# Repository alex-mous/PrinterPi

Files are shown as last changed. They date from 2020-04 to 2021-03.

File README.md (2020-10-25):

# PrinterPi
### An automatic web parser and packing list printer using a Raspberry Pi and a thermal printer
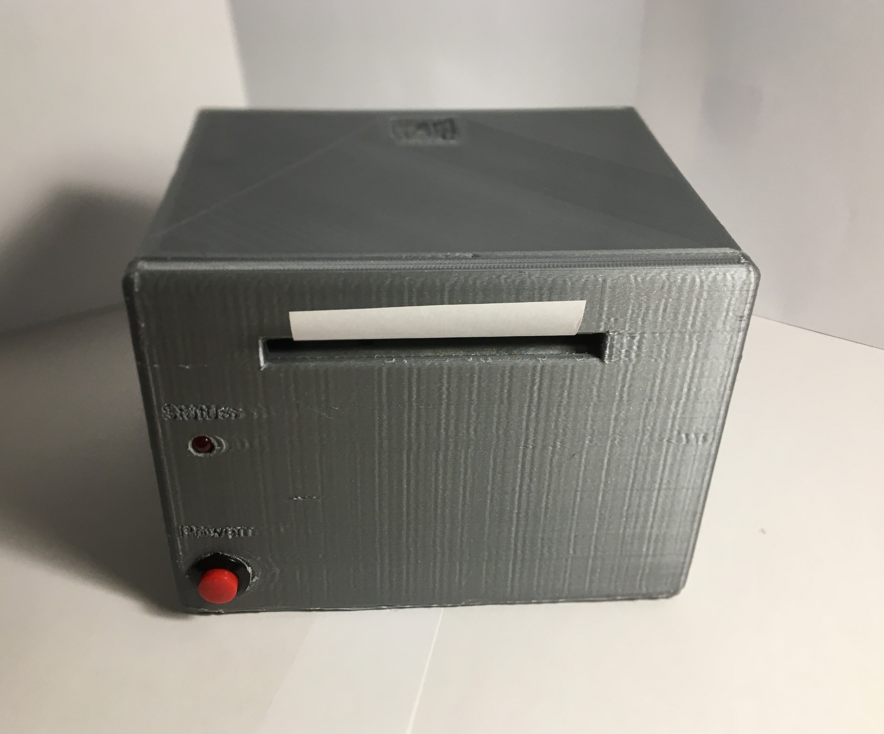
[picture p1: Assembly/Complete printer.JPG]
Completed PrinterPi project


### Parts and Materials
- Raspberry Pi Zero W with [Raspbian Jessie Lite](http://downloads.raspberrypi.org/raspbian_lite/images/raspbian_lite-2017-03-03/2017-03-02-raspbian-jessie-lite.zip) installed (this version is important if you want to make the file system read-only; see the optional last step)
- 3D prints of the files in the "3D Files" directory
- Soldering equipment
- A thermal printer and required paper (DP-58C)
- DC power supply (12V 5A) with a corresponding plug for the barrel jack
- Wire
- Some stripboard
- Electronic components as shown in the [wiring diagram](/Assembly/Wiring.pdf) and [BOM](/Assembly/PrinterPi%20BOM.csv) and pin headers and sockets (1-pin width)
- M2.5x12 and M2x6 machine screws
- A sacrificial pencil for the roll holder

### Software Setup
You will need access to the Raspberry Pi (through either SSH or console) to install the software.

After booting up the Raspberry Pi, we need to setup the WiFi; open the WiFi configuration file:
```
sudo nano /etc/wpa_supplicant/wpa_supplicant.conf
```
And then add the following to the bottom:
```
network={
    ssid="YOUR_SSID_HERE"
    psk="YOUR_PSK_HERE"
}
```

Next, get the IP address of the Raspberry Pi (and write it down; we will be using the IP address later to communicate with the extension):
```
sudo ifconfig
```
After this, run `raspi-config` to setup some further settings as shown in the table below

Option | Description
---------- | ----------
Change User Password | Change to something more secure as the Raspberry Pi will be available the network
Hostname | Name your Pi so that it can be addressed without an IP address
Interfacing Options -> SSH | Enable
Interfacing Options -> Serial</td><td>Disable console, enable serial
Boot Options -> Desktop/CLI -> Console Autologin</td><td>Enable this so that the script will run automatically

Now, you can either use the precompiled code from the Releases page. (You may need to install the Java Runtime Environment with `sudo apt-get install default-jre`), or compile the code yourself using the method below:

To compile the code, we need to install Java on the Raspberry Pi.  Run the following commands to do this:
```
sudo apt-get update
sudo apt-get install openjdk-8-jdk -y
```
Finally, download a copy of the code in the "PrinterPiServer" directory in this repository and place the files in the home directory of the Raspberry Pi.

You will need to compile the code before it can run; this can be done with the following command:
```
javac *.java
```

(*continue here if using precompiled code*)
Additionally, we need to make the power button management script executable with the following command:
```
sudo chmod +x power_button.sh
```
To make the Raspberry Pi run the code automatically on boot, add a couple of lines of code to the .bashrc file, which runs when the user logs in (done automatically on boot up with the console autologin selection in raspi-config). Open up the file with:
```
sudo nano ~/.bashrc
```
And add the following lines to the end:
```
/bin/bash /home/pi/power_button.sh&
stty -F /dev/serial0 115200
java -cp /home/pi Main&
```
Finally, we need a logo for the receipt to print. Generate this from any size and color picture with the Python code in the Logo directory with the following steps:
- Take a copy of your logo and place it into the Logo directory (rename it to Logo_in.png)
- Next, open and run the Python program "Image Processing.py"
- This will create a binary file, Logo.bin. You need to copy this file and place it into the directory with the other code on the Raspberry Pi for it to run

If you do not have a logo, just create an empty file called Logo.bin on the Raspberry Pi in the same folder as the PrinterPiServer code.

#### Optional additional steps
- Use HOSTNAME.local instead of an IP address, where HOSTNAME is the hostname set with raspi-config. This should work automatically on Macs and Linux/Unix computers. For Windows machines, you will need to install Bonjour. To implement this system, change the value in IP_ADDRESS.txt to HOSTNAME.local.</li>
- Convert Raspberry Pi to read-only to remove the need for power button and risk of SD card corruption such as at
	https://medium.com/@andreas.schallwig/how-to-make-your-raspberry-pi-file-system-read-only-raspbian-stretch-80c0f7be7353</li>

### Wiring
First, solder together the circuit board as shown below (reference the pictures with the <a href="/Assembly/Wiring.pdf">Wiring diagram</a> (__Note: you will need to cut some of the traces, so please look carefully.__)

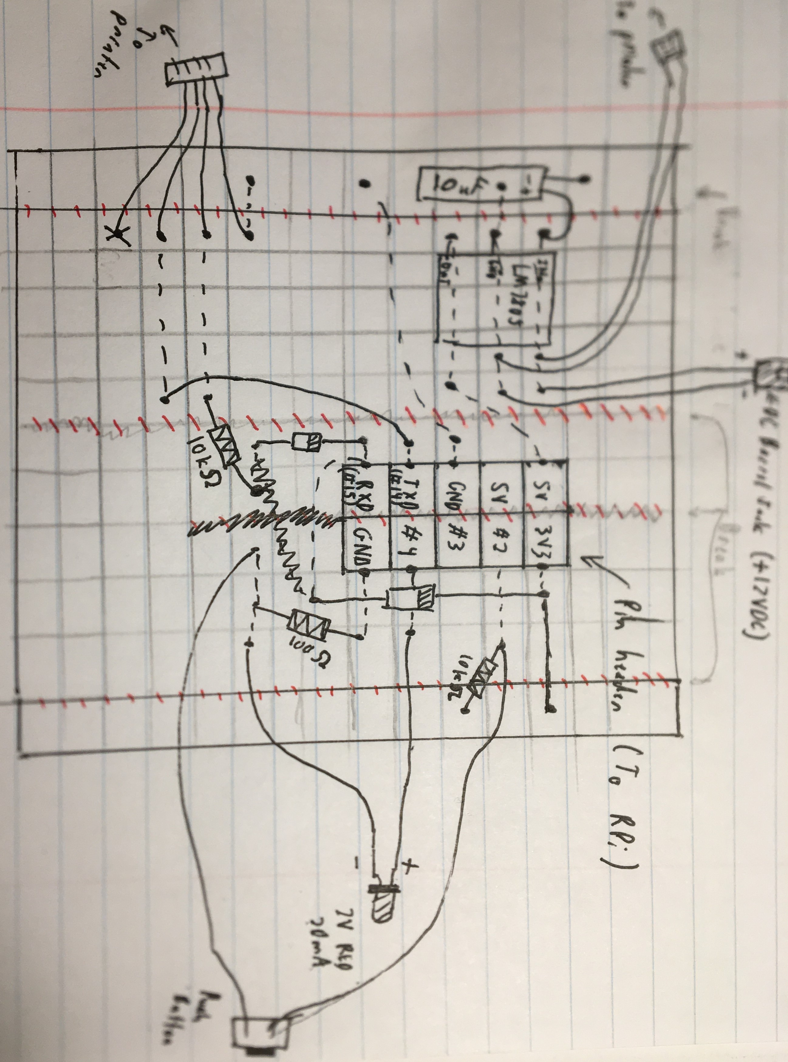
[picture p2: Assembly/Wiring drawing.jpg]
Drawing of the wiring of the ciruit board
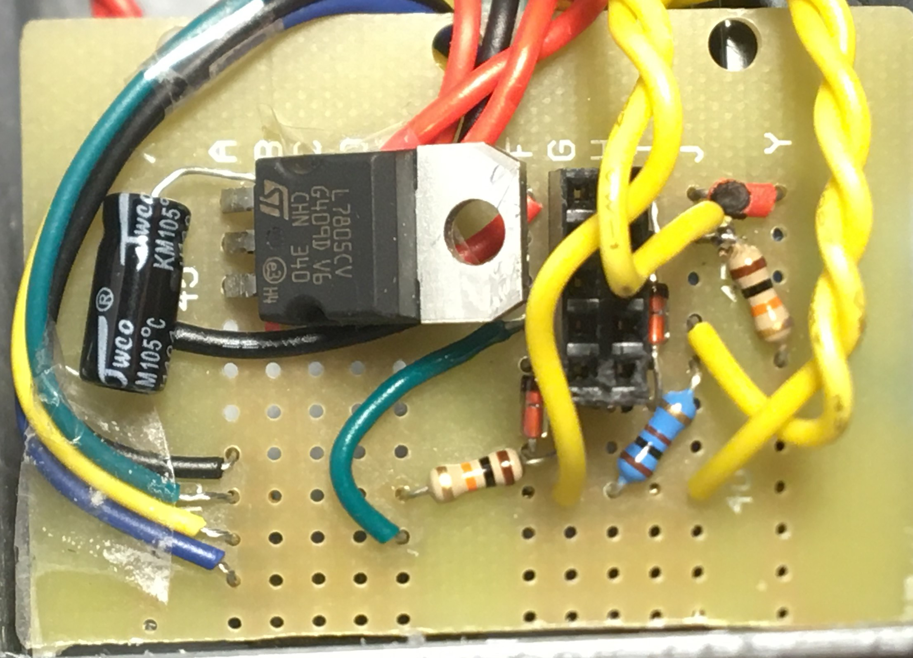
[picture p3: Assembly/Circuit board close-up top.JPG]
Close-up of the components on top of the circuit board


Next, solder up the power jack and thermal printer cables (power and data; these will need to be spliced) to the wires from the circuit board. The LED and power button also need to be soldered, but in this case to pin headers instead of directly to the circuit board.

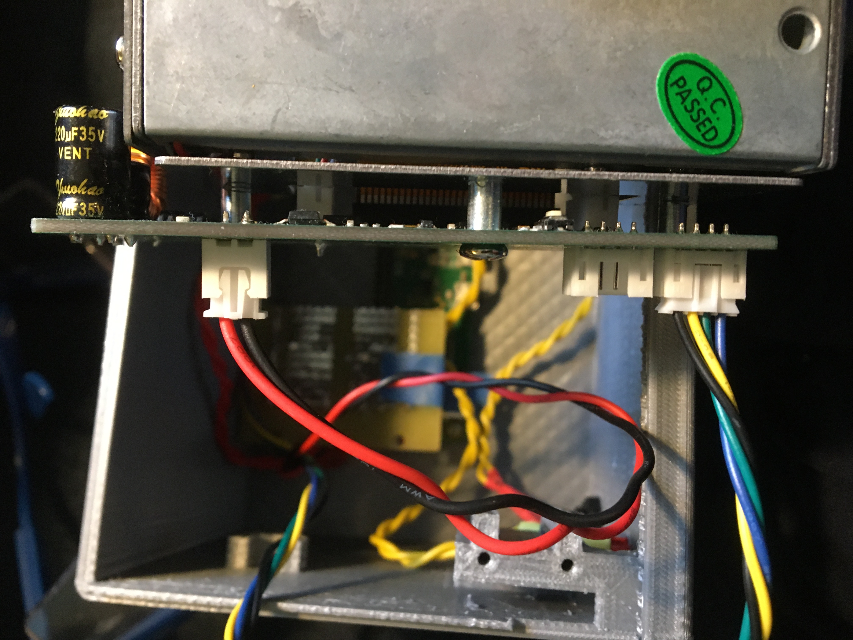
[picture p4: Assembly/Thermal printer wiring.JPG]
Wiring connections to the thermal printer
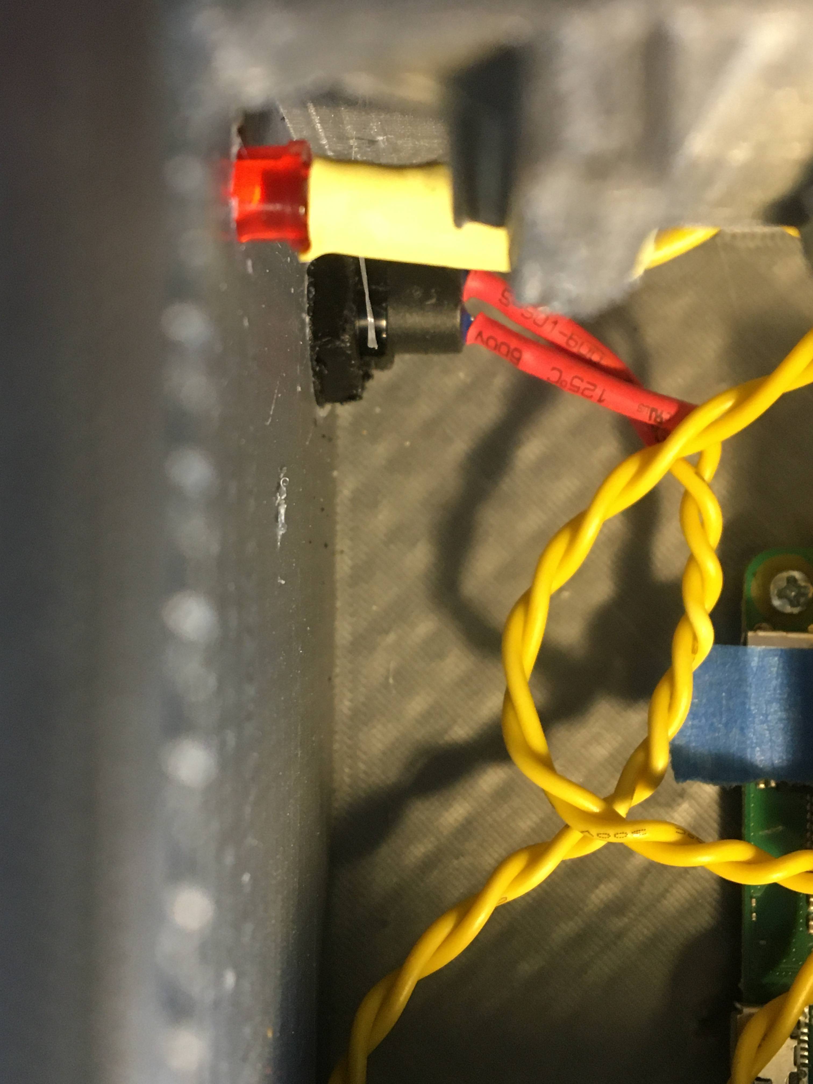
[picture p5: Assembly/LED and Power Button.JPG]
Close-up of the LED and power button installation


Finally, connect all corresponding cables and sockets and check that the Raspberry Pi boots and runs successfully.

### Assembly
Now that the circuit is complete, assemble the printer as shown below.
#### Raspberry Pi and Circuit
First, install the Raspberry Pi. Using the M2x6 screws, mount the Raspberry Pi with the GPIO header to the right and ports and connectors to the left. Next, insert the circuit board on top of the Raspberry Pi's GPIO header. You can use tape and/or a mirror to help line up the pins. Now install the power button and LED; the former needs to have the nut screwed on from the back, whereas the latter is just a press fit.

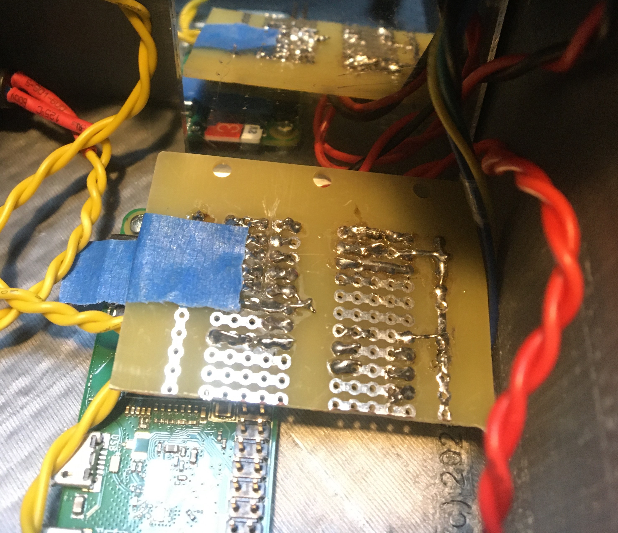
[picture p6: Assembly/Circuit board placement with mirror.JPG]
Installation of the Raspberry Pi and circuit board


#### Thermal Printer
Before the printer will fit, you will need to remove one screw from each side of the printer as highlighted in the picture below. Then just slot the printer in at an angle. Add the M2.5 screws and the printer is installed.

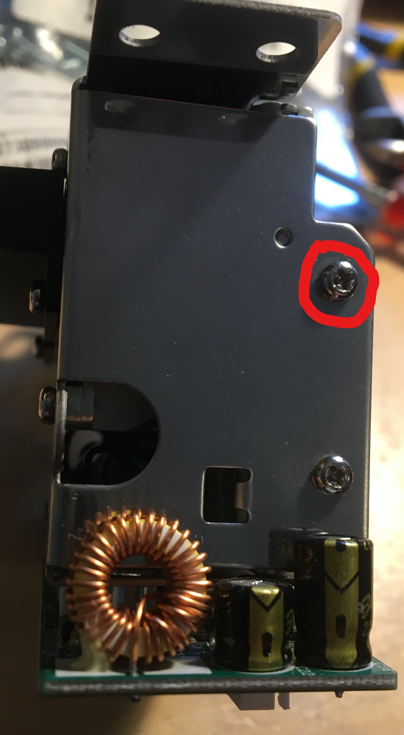
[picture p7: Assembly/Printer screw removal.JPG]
Screws that need to be removed from the thermal printer highlighted
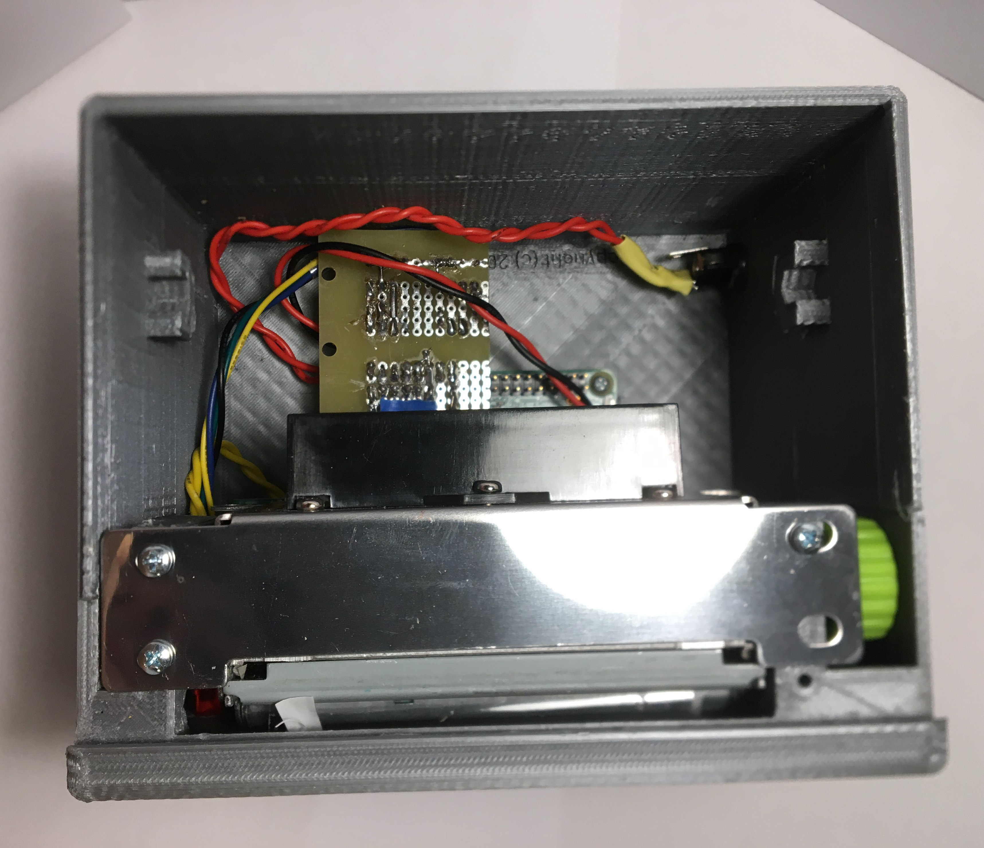
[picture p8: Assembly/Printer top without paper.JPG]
Overview of the top of the printer without the paper roll


#### Paper Roll
To keep the paper roll easily accessible, use a pencil as a roll holder. First, you will have to cut it down to the correct length, and (maybe) trim the ends to fit. This is easily done with a craft knife.

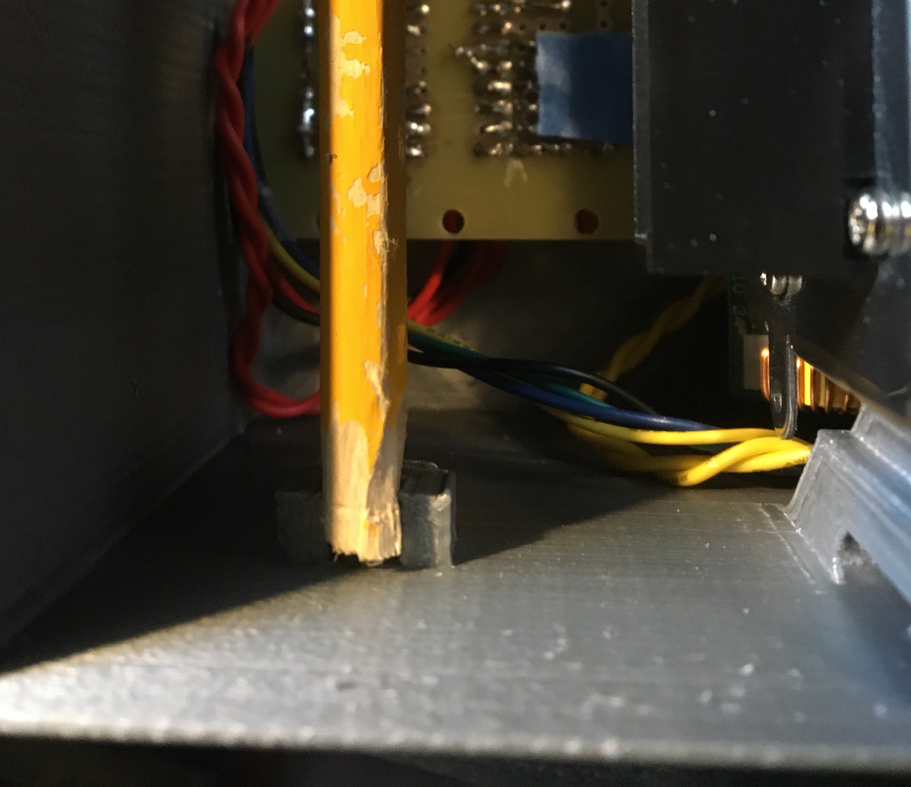
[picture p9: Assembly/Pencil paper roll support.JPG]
Pencil used as a paper roll holder for the thermal printer
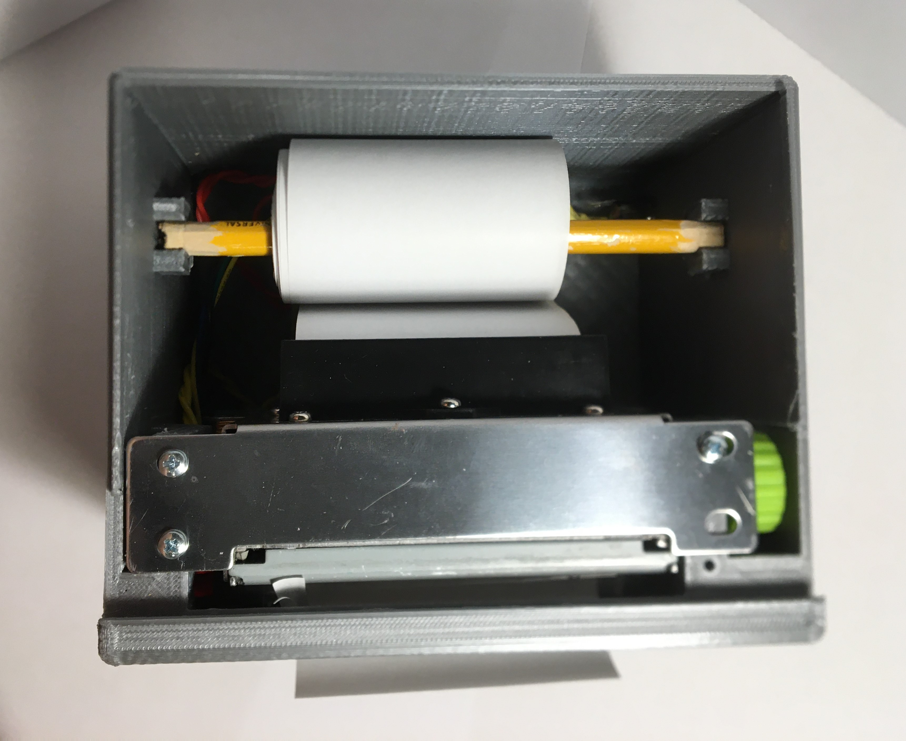
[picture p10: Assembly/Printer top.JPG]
Overview of the top of the printer with the paper installed


#### Final Steps
Place a roll of paper on the pencil and feed it into the printer. ___Note: you may need to install some tape to prevent paper from curling up in the gap between the printer's output and the lid.___ Finally slide on the lid, and it should click into place (if not, sand and trim until it fits).

### Client Setup - Chrome Extension
To install the Chrome Extension, navigate to <a href="chrome://extensions">chrome://extensions</a> and check the box in the upper right corner reading "Developer mode." After this, click the "Load unpacked" button, and select the folder containing the extension. Finally, after the extension appears, you can uncheck the "Developer mode" box. Also, this extension can be installed <a href="https://chrome.google.com/webstore/detail/printerpi/dgmejpjohdfgiolaailhklbbkfchidkl?hl=en-US">from the Chrome Extension Store.</a> *(Note: this extension may be a previous version, so please check the versions before installing)*

### Usage
#### Printing
Click on the extension on Google Chrome, navigate to either the eBay Print a shipping label page or the PayPal Activity page (make sure to open at least one transaction; the data gathered will appear if successful), ensure that the printer is up and running, press the "Parse Data" button to read the data off of the webpage, and finally press the "Print Receipt" button. If all is well, a message "Successfully sent data to the printer" will appear, the printer's light will start flashing and the paper will print. If not, please see Troubleshooting below. Also, there is a "Save Data" button to save the data into the extension, so that when it is reopened, the same settings will show. Finally, you can generate and print #10 size envelopes with the buyer's address, your address, and an optional custom logo by pressing the "Print Envelope" button. *Note: before using the printer for the first time, you will need to set up the options. Navigate to this page by using the button at the very bottom of the Chrome Extension and fill in the fields as directed (including the IP address from earlier [written in the form of IP_ADDRESS:9321, where 9321 is the custom printer network port])*
#### Booting Up and Shutting Down
On boot, the printer will flash its LED slowly to indicate that the printer is ready for use. When you want to shut it down, press and hold the power button until the LED turns off. Then disconnect the power supply.
#### Note
Due to some insufficiencies with the PayPal and eBay GUIs the SKUs cannot currently be parsed nor the quantity on PayPal so these need to be manually entered.

### Troubleshooting
#### LED not flashing after boot
- The SD card might be corrupted, or something may have happened to the code. Please SSH into the Raspberry Pi or re-install the software.
#### Printer not printing
- If the LED light is flashing, that means that there is an issue with the printer. The most likely cause is that it is out of paper.
- Otherwise, the host is probably not connecting properly to the Raspberry Pi.
#### Power button not shutting down the Raspberry Pi
- Check the wiring of the power button and note that you need to hold the power button down until the LED turns off. At this point, it is safe to remove power.
#### Chrome Extension errors
- Try checking the Options, reinstalling the extension (and looking at the JavaScript console) or running the PrinterPiServer code on the Raspberry Pi in a console and watching the output.

### License
Copyright (C) 2020  PolarPiBerry
All work is licensed under the GNU General Public License (see LICENSE)

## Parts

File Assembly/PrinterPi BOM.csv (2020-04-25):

Number | Part
C1 | Capacitor, 10uF
C2 | Capacitor, 0.1uF
D1 | LED, 2V Red
D2 | Diode, 1N4148
D3 | Diode, 1N4148
J1 | Wires, To Printer Data
J2 | Wires, To Printer Power
J3 | 2.1mm Barrel Jack
J4 | 2x8 pin header, To RPi
J5 | Wires, To Push Button (Push button is part R13-502)
R1 | Resistor, 100
R2 | Resistor, 10K
R3 | Resistor, 10K
U1 | Linear voltage regulator, LM7805

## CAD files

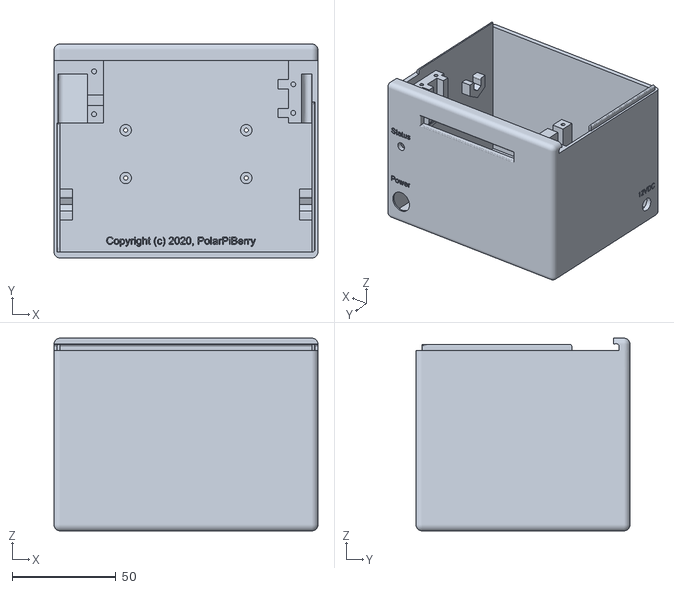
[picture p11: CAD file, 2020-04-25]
3D Files/Main V2.1.stl
127.0 x 103.0 x 92.7

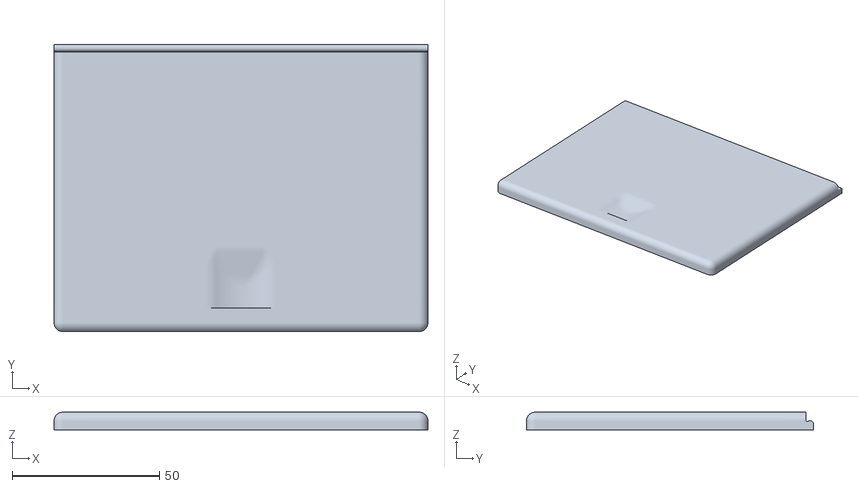
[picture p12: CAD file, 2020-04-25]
3D Files/Lid V1.1.stl
127.0 x 97.5 x 6.00

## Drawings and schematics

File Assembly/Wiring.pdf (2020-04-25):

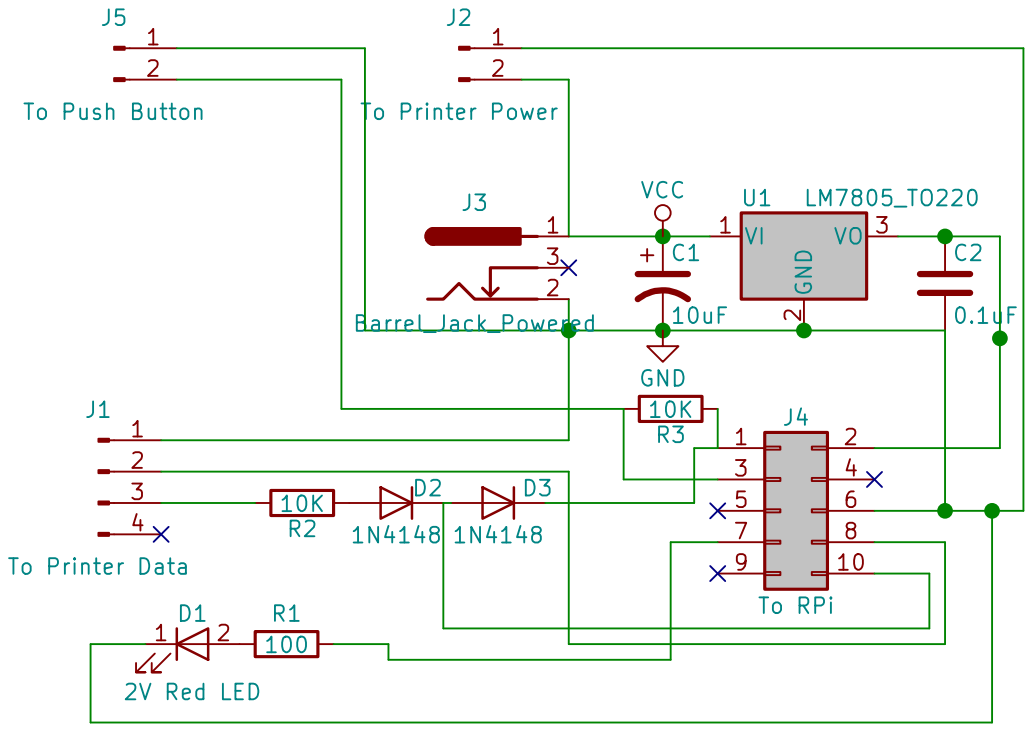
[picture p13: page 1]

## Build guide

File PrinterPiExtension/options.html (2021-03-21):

### PrinterPi Settings

###### Version: 7.2.5

###### Loading...

##### Return Address

##### Return Address Custom Envelope Logo

Choose a logo (optional)

Clear Logo

Upload an image file to print at the top of the return address. Note that transparency in PNGs will become black. To remove the logo, click Clear Logo or upload a new one in its place.

##### Receipt Message

This is the message that will be printed at the bottom of the receipt. Newlines will be doubled (forming paragraph spacing)

##### Printer IP Address

Please supply a valid IP address or domain name. An invalid IP/domain name will result in an error while connecting to the printer.

##### Save Receipts

Yes

No

###### Subdirectory of Download folder

Please do not supply absolute paths or use back-references (".."). These will result in an error

##### Automatic Page Parsing

(automatically read if valid)

Yes

No

Automatically parse page if the data on it is valid. If not, the stored data will be displayed and you'll have to manually parse data with "Parse Page".

Save Settings

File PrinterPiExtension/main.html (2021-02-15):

### PrinterPi

An automatic web parser and packing list printer using a Raspberry Pi and a thermal printer

##### Not connected

Parse Page Show Saved Parse File

Print All Receipts

Print All Envelopes

Save

##### Current Order

Print Receipt Print Envelope Remove order

###### Address

###### Shipping

###### Tax

###### Subtotal❔

###### Items Purchased

Description | Total | QTY | SKU

Add row

PrinterPi Settings

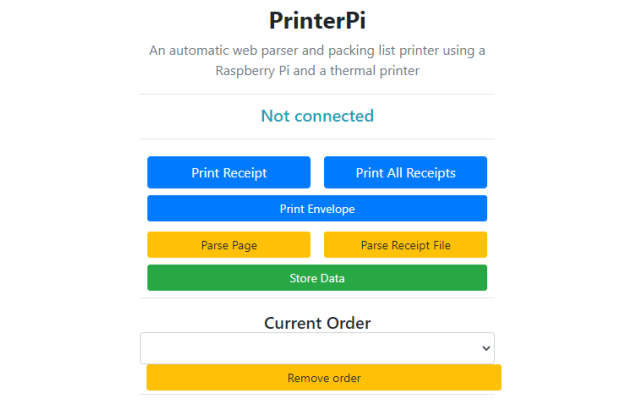
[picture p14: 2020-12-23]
Assembly/Screenshot 2020-12-21 002440.png

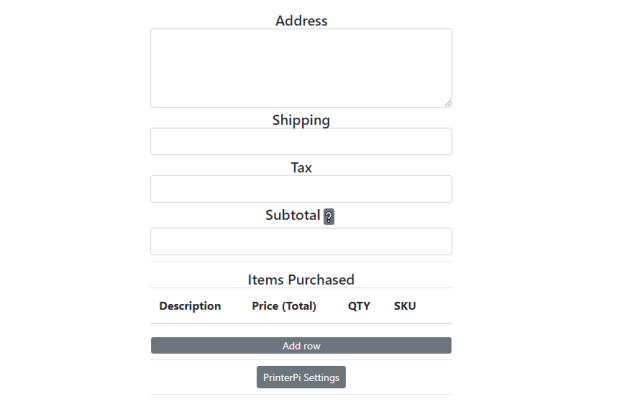
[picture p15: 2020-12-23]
Assembly/Screenshot 2020-12-21 002401.png

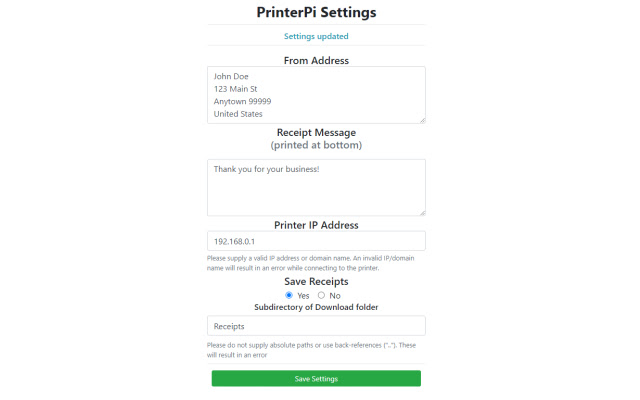
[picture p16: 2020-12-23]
Assembly/unnamed.jpg

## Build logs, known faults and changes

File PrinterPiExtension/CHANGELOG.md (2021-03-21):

# Changelog
All notable changes to the PrinterPiExtension code will be documented in this file.

The format is based on [Keep a Changelog](https://keepachangelog.com/en/1.0.0/),
and this project adheres to [Semantic Versioning](https://semver.org/spec/v2.0.0.html).

## [7.1.1] - 2021-01-17
### Changed
- Fixed rounding error with tax field when on eBay Regular page (causing incorrect values to be present in resulting receipt)

## [7.2.0] - 2021-02-15
### Changed
- Fixed bug with new eBay update
- Changed extension logo
- Improved interface for adding/removing orders (changed to more logical labelling system and increment/decrement when removing orders)
- Added bulk printing for envelopes

## [7.2.1] - 2021-02-15
### Added
- Add saving to edited data fields
### Changed
- Fix bug with printing all envelopes

## [7.2.2] - 2021-02-27
### Changed
- Fix interface to work with latest eBay Print Label page

## [7.2.3] - 2021-03-07
### Added
- Add support for no SKU items in Bulk Shipping Label printing

## [7.2.4] - 2021-03-08
### Added
- Add support for no SKU items in Regular Shipping Label printing

## [7.2.5] - 2021-03-21
### Changed
- Fix bug with non-invoice payments on PayPal
- Fix compatibility with eBay Bulk Shipping Label printing update

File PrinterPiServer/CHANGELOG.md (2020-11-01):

# Changelog
All notable changes to the PrinterPiServer code will be documented in this file.

The format is based on [Keep a Changelog](https://keepachangelog.com/en/1.0.0/),
and this project adheres to [Semantic Versioning](https://semver.org/spec/v2.0.0.html).

## [1.1.0] - 2020-11-01
### Added
- Support for Tax field in transmitted data packets

## [1.0.0] - 2020-09-15
### Added
- Add support for transmitting to and from addresses, as well as custom message
### Changed
- Implemented direct HTTP connections via custom port
- Update way receipts are printed

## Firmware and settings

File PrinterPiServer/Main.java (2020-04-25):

/*
 *    Main.java - Main Java program; runs and controls all classes to create fully working printer system
 *
 *    Copyright (C) 2020  PolarPiBerry
 *
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
 *    You should have received a copy of the GNU General Public License
 *    along with this program.  If not, see <https://www.gnu.org/licenses/>.
 */

import java.util.*;
import java.io.*;

public class Main {
	static Queue<Packet> print_queue;
	static Printer printer;
	static Hardware hardware;
	static Pin led;

	public static void main(String[] args) throws IOException {
		PrinterServer server = new PrinterServer(); //Create the server
		printer = new Printer(); //Create the printer
		hardware = new Hardware();
		led = new Pin(4, 1); //BCM 4, output
		boolean stat = hardware.setup(led);
		System.out.println(stat);

		hardware.readyLEDFlash(led);

		System.out.println("-INFO- Server started. Waiting for print jobs...");
		print_queue = new LinkedList<Packet>();

		Thread mng = new Thread() {
			public void run() {
				try {
					while (true) {
						queueManager();
					}
				} catch (InterruptedException e) {
				}
			}
		}; //Start the print queue manager thread
		mng.start();

		while (true) { //Main loop - adds print jobs to queue
			Packet res = server.getPacket();
			if (res != null) {
				System.out.println("-INFO- New print job - adding to queue. Current queue size: " + (print_queue.size() + 1));
				print_queue.add(res); //Add job to print queue - automatically popped by queueManager() thread
			} else {
				System.out.println("-ERROR- Error recieving data from server. Please check the log file.");
				hardware.errorLEDFlash(led);
			}
		}
	}

	public static void queueManager() throws InterruptedException { //Queue manager; releases one print job - designed to be run in infinite loop by a separate thread
		if (print_queue.size() > 0) { //Run if more than one print job to be released
			hardware.printingLEDFlash(led);
			Packet job = print_queue.remove();
			try {
				System.out.println("-INFO- Releasing print job...");
				printer.print(job);
				Thread.sleep(1000); //Delay in between print jobs
			} catch (IOException e) {
				System.out.println("-ERROR- Error in releasing print job.");
			}
			System.out.println("-INFO- Print job complete. Current print queue size: " + (print_queue.size() + 1));
		}
		Thread.sleep(100); //Only need to check every second
	}
}

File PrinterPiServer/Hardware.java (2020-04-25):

/*
 *   Hardware.java - Provides a way to control the GPIO pins through the sysfs interface
 *
 *   Copyright (C) 2020  PolarPiBerry
 *
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
 *   You should have received a copy of the GNU General Public License
 *   along with this program.  If not, see <https://www.gnu.org/licenses/>.
*/


import java.io.FileWriter;
import java.io.FileReader;
import java.io.File;
import java.io.IOException;
import java.util.LinkedList;


public class Hardware {
	LinkedList<Pin> pins;

	public Hardware() {
		pins = new LinkedList<>();
	}

	public boolean setup(Pin p) { //Setup the BCM pin <pin> for reading/writing (<direction> is 0 for reading, 1 for writing))
		try {
			FileWriter gpio; //Used to point to sysfs GPIO files
			File temp = new File("/sys/class/gpio/gpio" + p.getNumber());
			if (!temp.exists()) { //Only export if the pin doesn't exist
				gpio = new FileWriter(new File("/sys/class/gpio/export"));
				gpio.write("" + p.getNumber());
				gpio.close();
			}
			gpio = new FileWriter(new File("/sys/class/gpio/gpio" + p.getNumber() + "/direction"));
			if (p.getDirection() == 0) { //Set input pin
				gpio.write("in");
			} else if (p.getDirection() == 1) { //Set output pin
				gpio.write("out");
			} else {
				throw new IllegalArgumentException("Direction must be either 0 or 1 for input or output, respectively");
			}
			gpio.close();
			pins.add(p); //Add for error checking when writing
			return true;
		} catch (IOException e) {
			e.printStackTrace();
			return false;
		}
	}

	public void close() { //General destructor method - closes all open GPIO pins
		try {
			for (Pin pin : pins) {
				FileWriter gpio = new FileWriter(new File("/sys/class/gpio/unexport"));
				gpio.write(pin.getNumber());
				gpio.close();
			}
		} catch (IOException e) {} //Nothing to do
	}

	private void _LEDFlash(Pin led, int loops, int duration) { //Helper method - to be run with a separate thread
		Thread thr = new Thread() {
			public void run() {
				try {
					for (int i=0; i<loops; i++) {
						write(led, 1);
						Thread.sleep(duration);
						write(led, 0);
						Thread.sleep(duration);
				}
				} catch (Exception e) {}
			}
		};
		thr.start();
	}


	public void readyLEDFlash(Pin led) { //Flash the LED to indicate status
		_LEDFlash(led, 10, 250);
	}

	public void errorLEDFlash(Pin led) {
		_LEDFlash(led, 75, 50);
	}

	public void printingLEDFlash(Pin led) {
		_LEDFlash(led, 25, 100);
	}

	public boolean write(Pin pin, int level) { //Write the pin <pin> value level (must be either 0 or 1)
		if (pins.contains(pin)) { //Uses Pin equals method to test that the pin exists and is in the correct direction
			try {
				FileWriter gpio = new FileWriter(new File("/sys/class/gpio/gpio" + pin.getNumber() + "/value"));
				if (level == 0 || level == 1) {
					gpio.write("" + level);
				} else {
					throw new IllegalArgumentException("Pin value must be either 0 or 1 for low or high, respectively");
				}
				gpio.close();
				return true;
			} catch (IOException e) {};
		}
		return false;
	}

	public int read(Pin pin) { //Read the pin <pin> value
		if (pins.contains(pin)) { //Uses Pin equals method to test that the pin exists and is in the correct direction
			try {
				FileReader gpio = new FileReader(new File("/sys/class/gpio/gpio" + pin.getNumber() + "/value"));
				String level = "" + gpio.read();
				gpio.close();
				return Integer.parseInt(level); //All successful, so return the value
			} catch (IOException e) {};
		}
		return -1; //Return -1 if failed
	}
}

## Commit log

2020-05-15 Version 2.0: Added editable fields and manual entry mode
    Added ablility to edit the fields before printing, tidied up interface, and added a manaul entry mode.
2020-09-14 Updates to software for new version of eBay and corrections to README
    [Hardware.java, Main.java]
2020-09-21 Update to v5.0: add envelope printing
2020-09-21 Update to v5.1: Add to README and remove some bugs in PrinterPiExtension
2021-02-15 Update to v7.2.1: add envelope printing
2021-03-08 v7.2.3: Add support for no-SKU items in Bulk Shipping Label printing
2021-03-09 v7.2.4: Add support for no-SKU items in Regular shipping label printing

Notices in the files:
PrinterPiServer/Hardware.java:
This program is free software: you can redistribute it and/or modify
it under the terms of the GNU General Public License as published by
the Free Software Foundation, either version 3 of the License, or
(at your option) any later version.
